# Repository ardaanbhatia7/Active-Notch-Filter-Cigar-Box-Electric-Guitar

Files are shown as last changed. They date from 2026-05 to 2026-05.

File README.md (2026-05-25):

# Active Notch Filter for Cigar Box Electric Guitar

A complete analog hardware project that designs, simulates, and demonstrates an **active notch filter** for removing unwanted frequency content in a cigar box electric guitar signal path.

This repository contains the simulation files, PCB/schematic design files, demonstration videos, and the project report used to document the full design/build process.

---

## Project Overview

This project compares passive and active notch filter approaches, then implements an active design suitable for guitar signal conditioning.

### What this project demonstrates
- Analog filter design (passive + active notch topologies).
- LTspice simulation workflow and AC/frequency-response verification.
- Practical op-amp implementation and gain staging for instrument-level signals.
- PCB and schematic implementation in KiCad for manufacturable hardware.
- End-to-end hardware demonstration in a real guitar context.

---

## Repository Contents

- `Ardaan_EE202_FinalProject_Report.pdf`  
  Full final report with design rationale, analysis, calculations, and results.
- `ActiveNotchFilter.asc`  
  LTspice schematic for the active notch filter implementation.
- `PassiveNotchFilter.asc`  
  LTspice schematic for passive notch filter baseline/comparison.
- `1719.kicad_sch`  
  KiCad schematic source for the hardware design.
- `1719.kicad_pcb`  
  KiCad PCB layout source for the hardware implementation.
- `Yash_Ardaan_NotchFilter_Demo.mp4`  
  Video demo focused on notch filter behavior/performance.
- `Yash_Ardaan_Guitar_Demo.mp4`  
  Video demo of the guitar setup and practical output.

---

## Technical Snapshot

From the simulation files in this repo:

- Passive network uses a twin-T style RC arrangement with representative values such as:
  - `R1 = 10k`, `R2 = 10k`, `R3 = 5k`
  - `C1 = 81.2n`, `C2 = 81.2n`, `C3 = 162.4n`
- Active simulation includes op-amp stages and ±9 V supplies.
- Active design includes feedback and buffering stages to improve notch depth/behavior compared to a purely passive implementation.
- Hardware design references an LM324-class op-amp implementation in KiCad.

> The complete derivation, measured/simulated plots, and design decisions are documented in the report PDF.

---

## How to Open / Reproduce

### 1) LTspice simulations
1. Open `PassiveNotchFilter.asc` in LTspice.
2. Run AC analysis and inspect notch behavior.
3. Open `ActiveNotchFilter.asc`.
4. Run AC analysis and compare notch depth/shape and response.

### 2) KiCad hardware files
1. Open `1719.kicad_sch` in KiCad Schematic Editor.
2. Open `1719.kicad_pcb` in KiCad PCB Editor.
3. Review footprint assignment, routing, and board stackup.

### 3) Demonstration videos
- Watch `Yash_Ardaan_NotchFilter_Demo.mp4` and `Yash_Ardaan_Guitar_Demo.mp4` for practical behavior and end-to-end usage.

---

## Resume-Focused Highlights

If you're reviewing this project from my resume, key evidence of engineering work includes:

- Designed and analyzed active/passive analog notch filters for audio-frequency applications.
- Performed simulation-driven validation using LTspice.
- Translated simulated circuits into PCB-realizable schematic/layout workflows in KiCad.
- Produced a formal project report and practical demo videos to communicate technical outcomes.

---

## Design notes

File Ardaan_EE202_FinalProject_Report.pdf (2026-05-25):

EE 202L - Linear Circuits

Final Project – The Corrupted Chord

Date: 5/6/2026

Ardaan Bhatia | 1309802147

This report describes the design and implementation of a notch filter for a cigar-box electric guitar. The objective of the circuit was to suppress the 196 Hz fundamental of the unfretted G string while preserving nearby notes as much as possible. The design was based on a twin-T bandstop filter, later sharpened with positive feedback so that the notch became narrow enough to reject the target note without strongly attenuating adjacent frequencies.

### 1. Filter Design

The starting point for the design was the passive twin-T notch filter assigned in the project handout. The details for theoretical calculations and derivations are shown in the handwritten screenshots below:

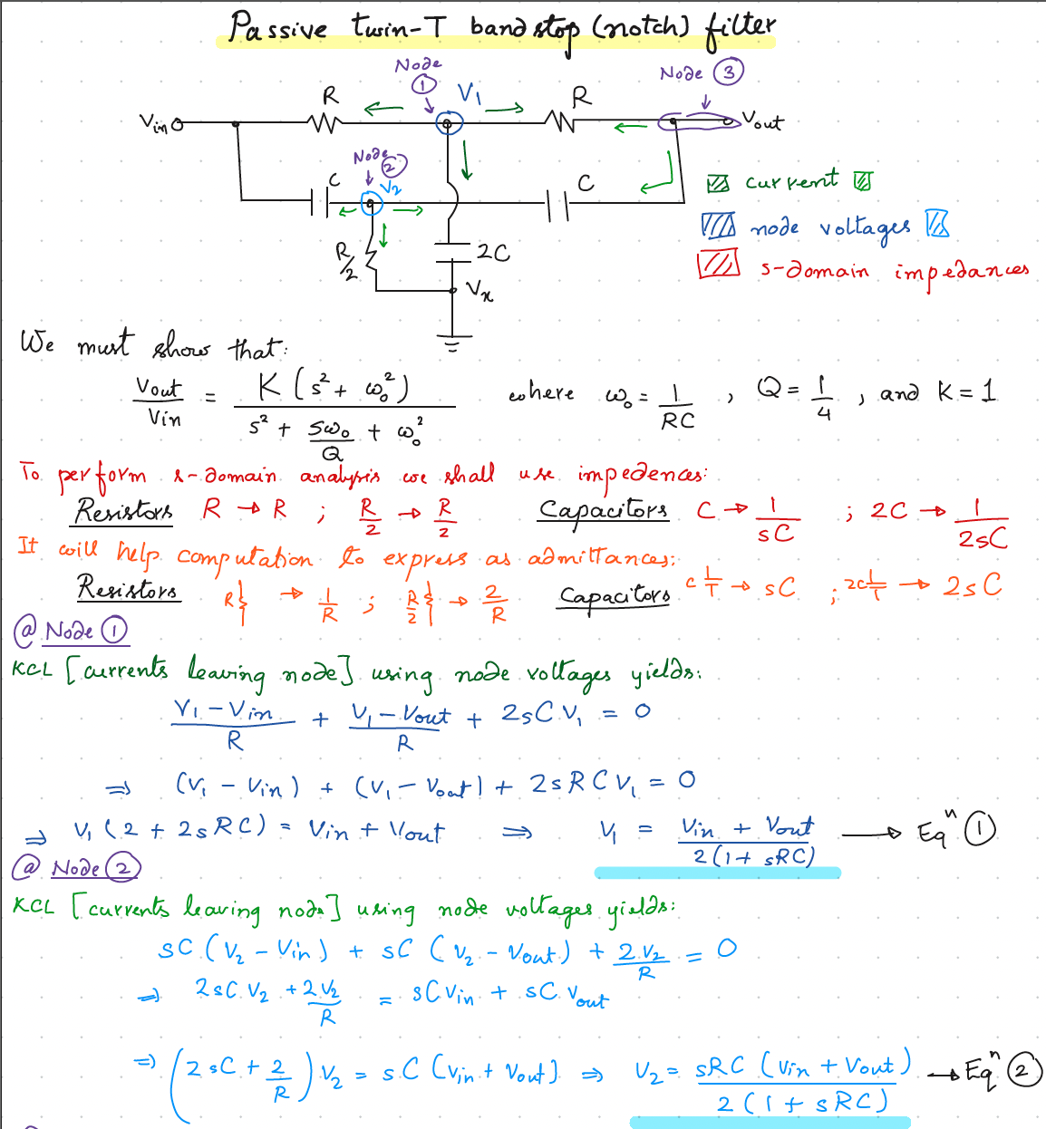
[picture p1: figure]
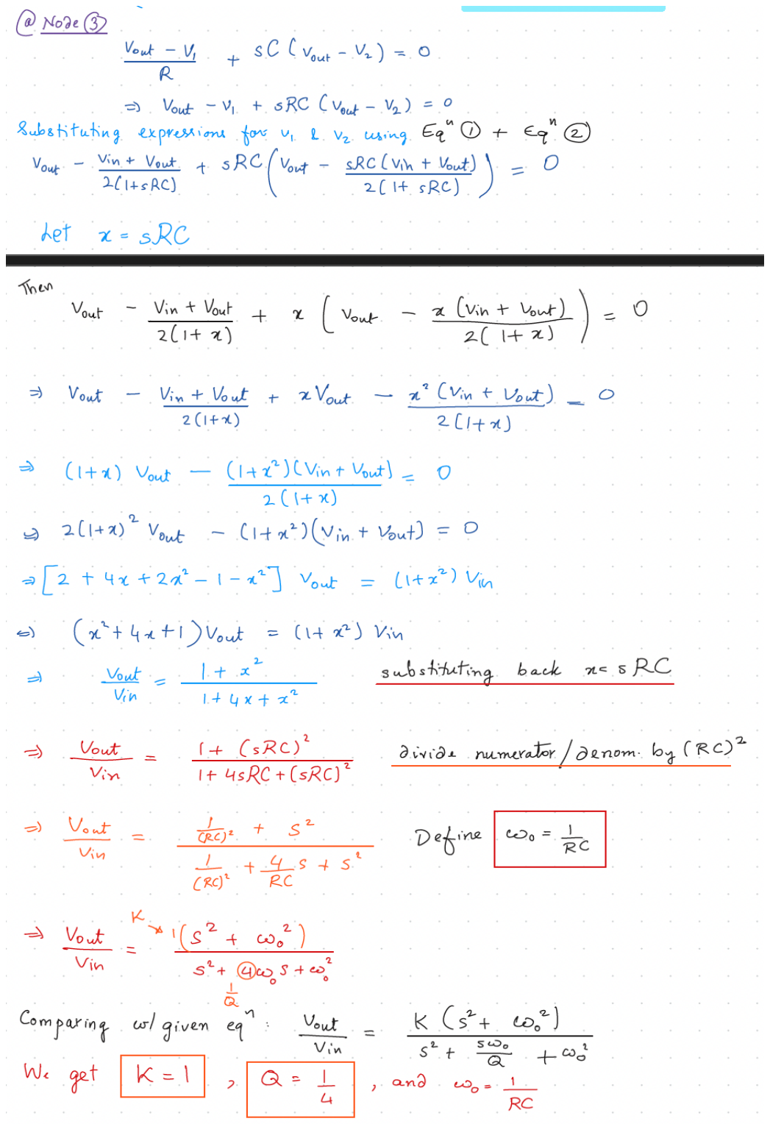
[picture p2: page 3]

Because K = 1, the passband gain is ideally unity. The numerator becomes zero when s = j w0, so the output ideally goes to zero at the notch frequency. Therefore, the notch frequency depends only on the product RC.

The project required the notch to occur at f0 = 196 Hz. To obtain a narrow notch, the passive network was modified with positive feedback so that the center node voltage became Vx = αVout, with α < 1. The handout states that the notch frequency remains unchanged and that the quality factor increases according to Q =

1
4(1−α)

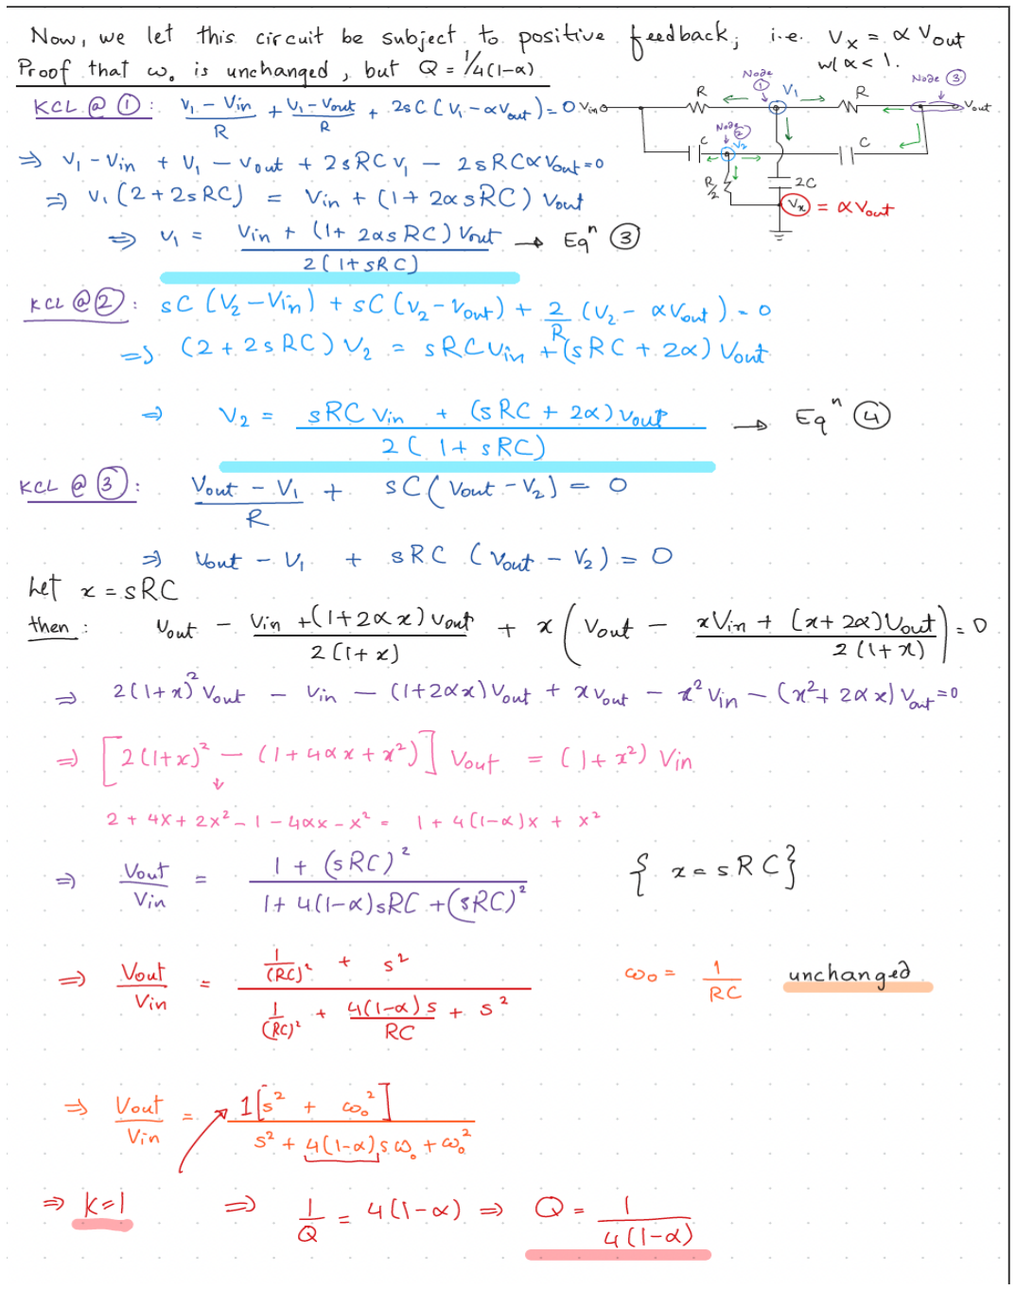
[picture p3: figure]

Furthermore, below is the justification for the choice of resistor and capacitor values:

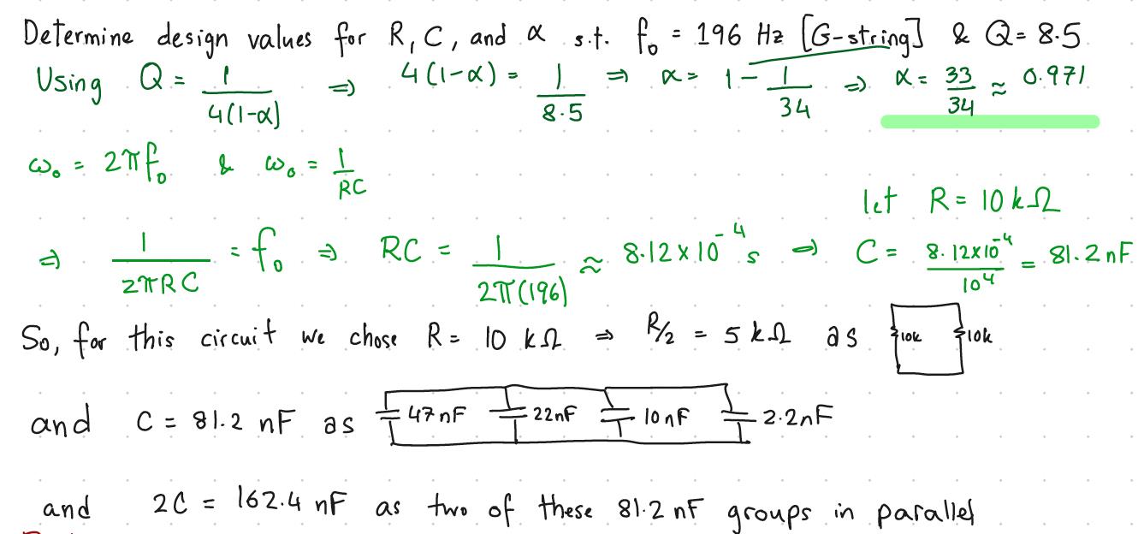
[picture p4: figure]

The positive-feedback factor alpha was produced with a voltage divider and two unity-gain buffers (OpAmps), as shown below:

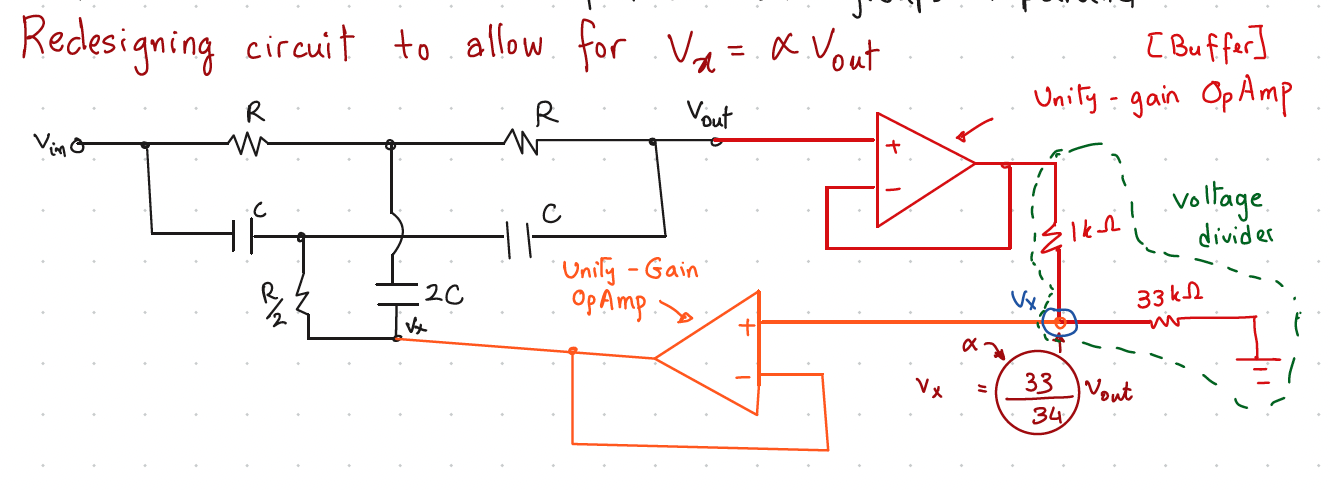
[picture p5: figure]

With these values, the theoretical notch frequency is 196 Hz and the theoretical quality factor is
8.5. This satisfies the project requirement that the filter reject the G-string fundamental while keeping the bandwidth narrow enough that nearby notes are minimally affected.

### 2. Simulations

We performed an AC simulation of the notch filter using a linear frequency sweep. A linear sweep is appropriate here because the magnitude changes rapidly in a relatively narrow

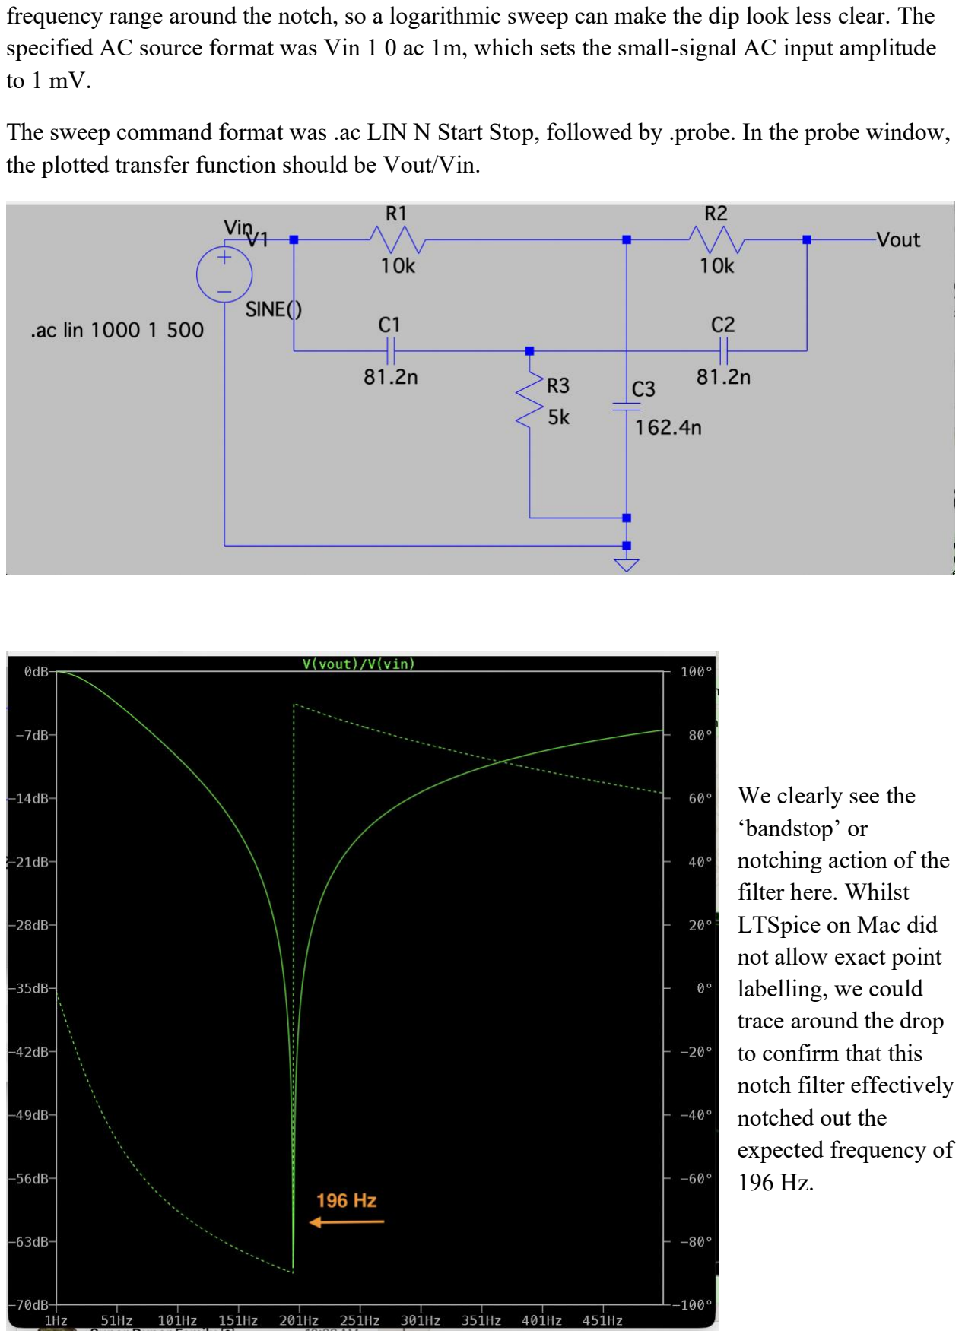
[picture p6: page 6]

frequency range around the notch, so a logarithmic sweep can make the dip look less clear. The specified AC source format was Vin 1 0 ac 1m, which sets the small-signal AC input amplitude to 1 mV.

The sweep command format was .ac LIN N Start Stop, followed by .probe. In the probe window, the plotted transfer function should be Vout/Vin.

We clearly see the
‘bandstop’ or
notching action of the
filter here. Whilst
LTSpice on Mac did
not allow exact point
labelling, we could
trace around the drop
to confirm that this
notch filter effectively
notched out the
expected frequency of
196 Hz.

For the active version of the circuit, we built the circuit below:

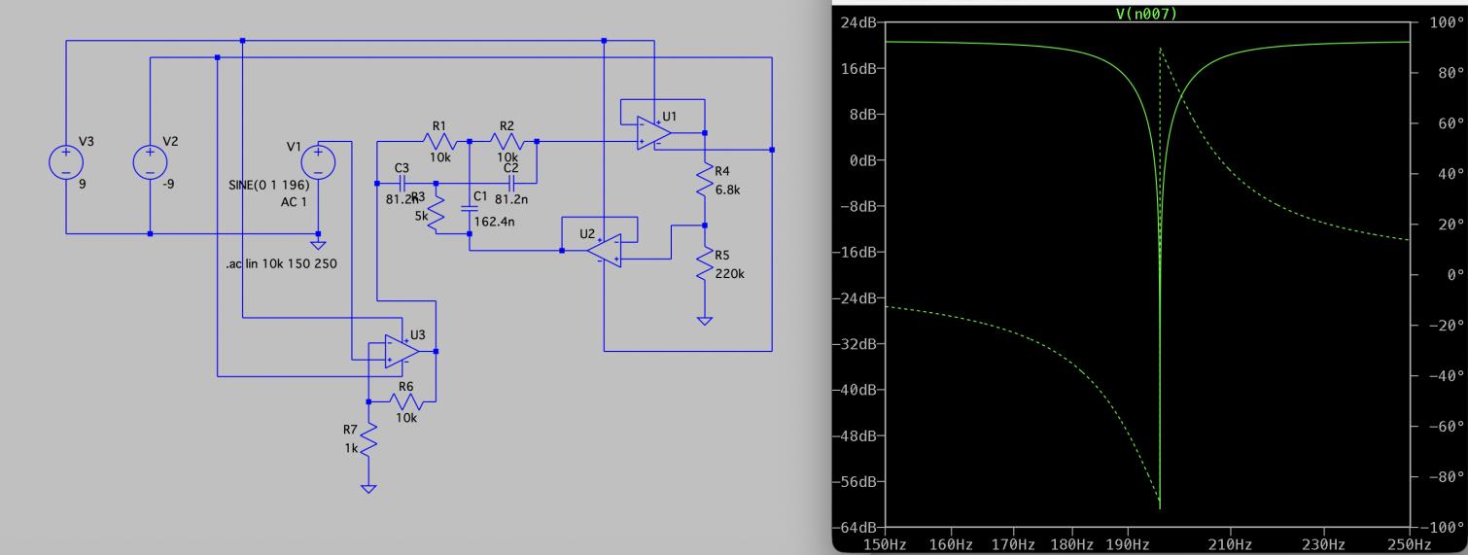
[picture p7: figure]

The expected result is a nearly flat passband close to 0 dB away from the notch, together with a deep, narrow dip centered near 196 Hz. Since the ideal transfer function has unity gain in the passband, the simulated response outside the reject band should remain near 1 in linear scale. At the notch frequency, the ideal output should approach zero, which appears as a very large attenuation in the magnitude plot.

The target quality factor is Q = 8.5, so the notch should be relatively narrow. Using BW = f0 / Q gives an approximate bandwidth of 196 / 8.5 = 23.1 Hz. This means the simulated attenuation should be concentrated in a small region around 196 Hz rather than extending broadly across the surrounding notes. When a component is shifted slightly from its nominal value, the expected response is that the notch moves away from 196 Hz and becomes less deep, which explains why component matching and post-build tuning are important.

The handout also states that the measured attenuation at f0 relative to the passband should be at least -20 dB. In ideal simulation, the notch will usually be deeper than this requirement, but practical component mismatch will reduce the achievable depth in the real circuit.

### 3. Guitar Assembly

The physical build of the project centered on converting the supplied wood and cigar box into a functional electric guitar body that could support the electronic filter board. We took a ‘standard guitar’ wood piece. During assembly, the pickup, bridge, strings, screws, and tuning hardware were installed so that the string path passed properly over the pickup.
Below is a labelled photograph of our guitar:

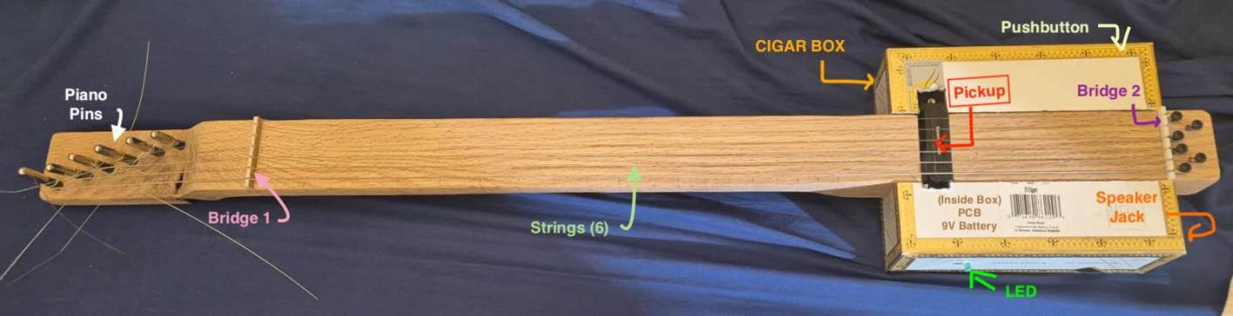
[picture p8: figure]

The final assembly stage required combining the mechanical and electrical portions of the project into a single working system. This included checking string tension, verifying that the pickup was mounted securely, and ensuring that the PCB and 9V battery were secured well inside the box. A successful mechanical build made the later electrical testing much easier because it reduced the number of non-electrical variables that could interfere with the checkoff.

### 4. PCB Design

After the filter concept was confirmed on the breadboard, the circuit was transferred into KiCad for schematic capture and PCB layout. The schematic included the twin-T network, the positive-feedback divider, the op-amp buffers required to isolate the divider from the filter nodes, and the necessary power and connector interfaces for the pickup, battery, and speaker path.

Shown below is our schematic:

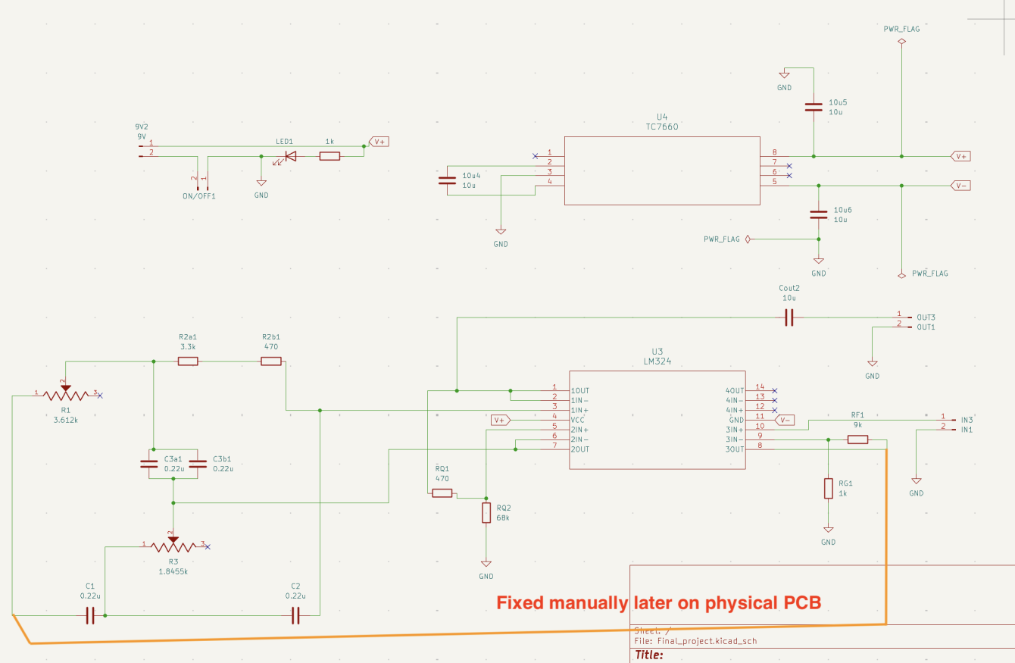
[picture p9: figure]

As seen by the orange wire, we didn’t have it originally, and later discovered this mistake post PCB fabrication. Fortunately, we could just manually solder on an additional wire to the pads.

Moving from breadboard to PCB required verifying every connection carefully because even a small wiring error could shift the notch frequency or destroy the desired filter shape.

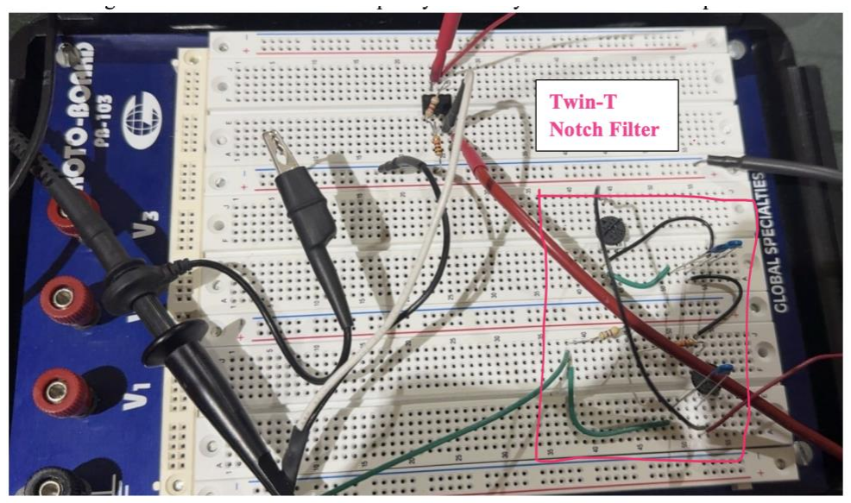
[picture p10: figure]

Component placement on the PCB was chosen to keep the filter network organized and to make soldering and debugging practical. The passive components associated with the notch network were grouped closely to reduce wiring confusion, while the active devices and power connections were arranged so that probing and rework remained manageable during testing. Clear labeling of polarity-sensitive parts was important for efficient, error-free soldering.

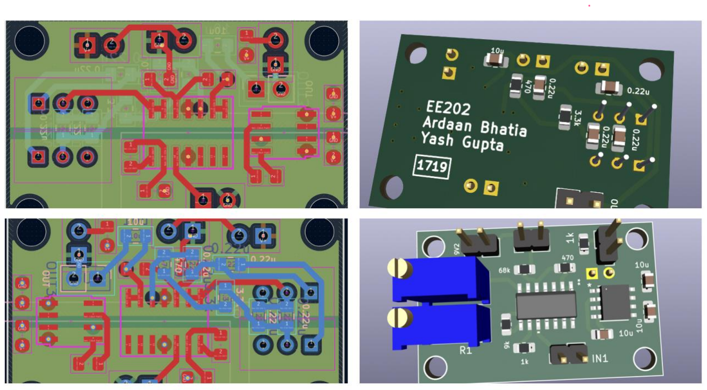
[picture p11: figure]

Once fabricated, the PCB was populated by soldering the op-amps, resistors, capacitors, and connectors onto the board. The assembled board was then checked for shorts, missing joints, incorrect orientations, and other common manufacturing or soldering defects before integration into the guitar. This stage served as the bridge between the theoretical design and the final functional instrument.

### 5. Final Electrical Testing

The completed PCB was installed inside the cigar-box body and connected to the pickup, speaker, and battery supply so that the full guitar system could be tested as an integrated design. In particular, the pickup output (hot black line) was soldered onto ‘IN’ pins of PCB and the ‘OUT’ pins of the PCB were wired to the speaker jack. Electrical testing focused on confirming that the active notch filter still behaved correctly after installation and that the instrument produced a clear output through the speaker.

The main performance checks were the notch frequency f0, the quality factor Q, and the attenuation at the target note relative to the passband. The expected result was a clear suppression of the 196 Hz G-note fundamental together with acceptable transmission of nearby notes, demonstrating that the notch was narrow enough for the intended application. To achieve this, we tuned the potentiometers. This behavior’s demonstration video is included in the Brightspace submission as ‘Yash_Ardaan_NotchFilter_Demo.mp4’.

Then, we finally got to try out the playing the guitar, it worked fluently when connected to the speaker. Whilst we observed that the G is audible, in spite of oscilloscope confirmation, it made sense due to harmonics and resonance associated with playing a guitar string. A successful final test therefore confirmed not only the circuit equations and simulations, but also the practical integration of the electronics into the guitar platform. A video demonstration named ‘Yash_Ardaan_Guitar_Demo.mp4’ is also attached in the Brightspace submission.

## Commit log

2026-05-25 full project with report
    [1719.kicad_pcb, 1719.kicad_sch]
2026-05-25 Add README for Active Notch Filter project
    Added detailed project overview, repository contents, technical snapshot, reproduction instructions, and resume-focused highlights for the active notch filter project.
